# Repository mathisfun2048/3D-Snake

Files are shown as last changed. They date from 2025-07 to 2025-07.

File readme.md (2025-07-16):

# 3-D Snake... but polished

## Description and Exigence

The basic framework of this project came from the undercity hackathon, where me and my teammates were able to scrapyard a prototype to work. This project is the same project but refined, adding a PCB to better manage wires and audio to better communicate to the user when the snake dies. Some minor software improvements have also been made (such as re-working the moving mechanism when the snake reaches the top pannel). 

Here's a pic of our prototype:


## Schematic and PCB

During prototyping, one of the hardest parts of the design was making sure all the gpio pins stayed in place! So, I made a pcb to help with wiring. 

Screenshot 2025-07-16 at 4 08 24 PM

Screenshot 2025-07-16 at 4 08 44 PM

Screenshot 2025-07-16 at 4 09 05 PM

Here's the full wirings with the raspberry pi:
Screenshot 2025-07-16 at 4 35 08 PM

## Firmware

This project is coded in circuitpython to run on a raspberry pi pico. Most of the firmware was written at the hackathon, including the snake's game engine and wrapping mechanisms. With my improvements, a audio mechanism was added, playing a sound when the game is played and a death "game over" sound. Additionally, the joystick movements was revised, however, its effacaciy will only be able to be tested once I build it and get to callibrate the joystick.

## CAD

Here it is! It's pretty bare-bones because I want access to all the gpio and other pins for debugging. 

full case together

Here's what the game will look like with the prototype cad we made at undercity! 



## BOM
|item |quantitiy|tot. cost|FIELD4 |
|---|---|---|---|
|Raspberry Pi Pico |1 |3.94 |https://www.aliexpress.us/item/3256805901509044.html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{"order":"588","eval":"1"}&pdp_npi=4@dis!USD!3.94!0.99!!!28.12!7.05!@2103245417526573392084861e1d15!12000044713099471!sea!US!6423725769!ABX&curPageLogUid=9vH35S108aDJ&utparam-url=scene:search&#124;query_from:&search_p4p_id=202507160215394922763879841710000065438_1 |
|8x8 Neopixel Matrix |5 |0.99 |https://www.aliexpress.us/item/3256806907950230.html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|
|Jumper Wire Kit |1 |2.94 |https://www.aliexpress.us/item/3256801814340687.html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 3.11!USD 2.94!!USD 2.94!!!@2103244817526478142373005ef927!12000018371624182!ct!US!6423725769!!1!0&_gl=1*1n0i64z*_gcl_au*MTk0MzAyNDY5MC4xNzUyNjI3MjM2*_ga*MTc1NDE4NzMwOC4xNzUyNjI3MjM3*_ga_VED1YSGNC7*czE3NTI2NDcxMjIkbzMkZzEkdDE3NTI2NDc4MzAkajE2JGwwJGgw&gatewayAdapt=glo2usa |
|7 Segment Display |2 |0.88 |https://www.aliexpress.us/item/3256806851785862.html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 |
|Joystick |1 |5.54 |https://www.aliexpress.us/item/3256807375670744.html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 |
|Stepper Motor |1 |6.05 |https://www.aliexpress.us/item/3256802068491329.html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 https://www.amazon.com/gp/product/B00PNEQKC0/ref=ewc_pr_img_3?smid=AWQBCGWISS7BL&psc=1 |
|Stepper Motor Driver|1 |2.25 |https://www.aliexpress.us/item/3256809082535036.html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 4.50!USD 2.25!!USD 2.25!!!@2101ead817526549979955339eefa0!12000048551339904!ct!US!6423725769!!1!0&_gl=1*1jo1tpj*_gcl_au*MTk0MzAyNDY5MC4xNzUyNjI3MjM2*_ga*MTc1NDE4NzMwOC4xNzUyNjI3MjM3*_ga_VED1YSGNC7*czE3NTI2NTMwNjIkbzQkZzEkdDE3NTI2NTQ5OTgkajU5JGwwJGgw&gatewayAdapt=glo2usa |
|9v Battery |2 |0 |n/a |
|9V Battery Wire |2 |1.35 |https://www.aliexpress.us/item/3256806021864359.html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 |
|I2C Audio Module |1 |2.13 |https://www.aliexpress.us/item/3256807442706139.html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 2.18!USD 2.13!!USD 2.13!!!@2103146c17526564969422213ebb51!12000041565703118!ct!US!6423725769!!1!0&_gl=1*zdge7z*_gcl_au*MTk0MzAyNDY5MC4xNzUyNjI3MjM2*_ga*MTc1NDE4NzMwOC4xNzUyNjI3MjM3*_ga_VED1YSGNC7*czE3NTI2NTMwNjIkbzQkZzEkdDE3NTI2NTY0ODMkajU4JGwwJGgw&gatewayAdapt=glo2usa |
|Speaker |1 |1.84 |https://www.aliexpress.us/item/3256805513567413.html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{"order":"521","eval":"1"}&pdp_npi=4@dis!USD!1.91!0.99!!!13.62!7.02!@2103247417526569339281477efc58!12000044410928207!sea!US!6423725769!ABX&curPageLogUid=dsVUW3rp1g8F&utparam-url=scene:search&#124;query_from: |
|header pins |1 |2.21 |https://www.aliexpress.us/item/2255800687544049.html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{"order":"3500","eval":"1"}&pdp_npi=4@dis!USD!2.21!0.99!!!2.21!0.99!@2101e07217526574650792034e0f2b!10000010058190554!sea!US!6423725769!ABX&curPageLogUid=oeRbzI77IVV5&utparam-url=scene:search&#124;query_from: |
|pcb |1 |6.22 |https://jlcpcb.com/ |
| | |36.34 | |

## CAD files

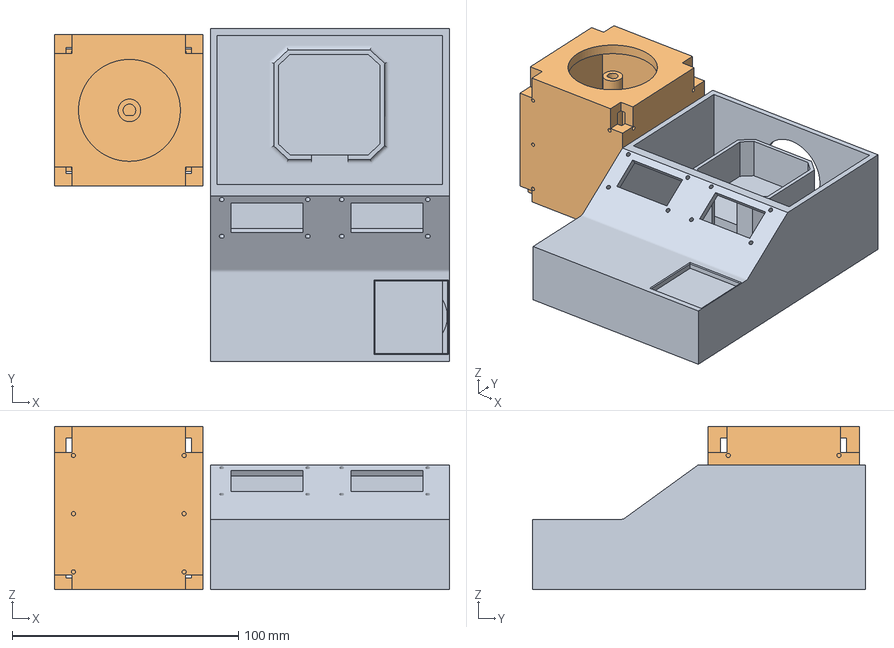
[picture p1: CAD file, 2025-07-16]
Production/Full Case.3mf
174.5 x 147.0 x 72.0 mm
LED Case.stl

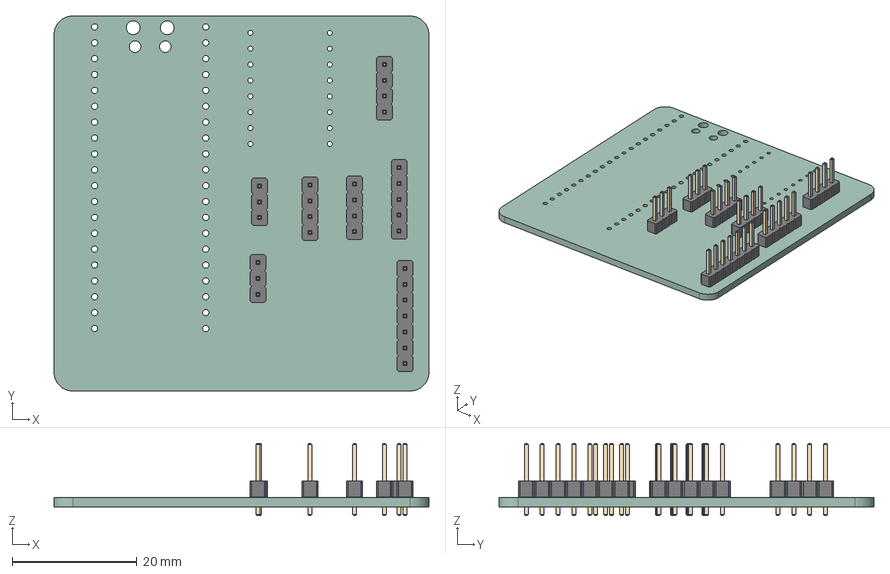
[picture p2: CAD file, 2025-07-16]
CAD/Snake_3D_PCB_STEP.step
60.0 x 60.0 x 11.5 mm
PinHeader_1x03_P2.54mm_Vertical x 2
PinHeader_1x04_P2.54mm_Vertical x 3
PinHeader_1x07_P2.54mm_Vertical
PinHeader_1x05_P2.54mm_Vertical
Snake_3D_KiCAD_PCB

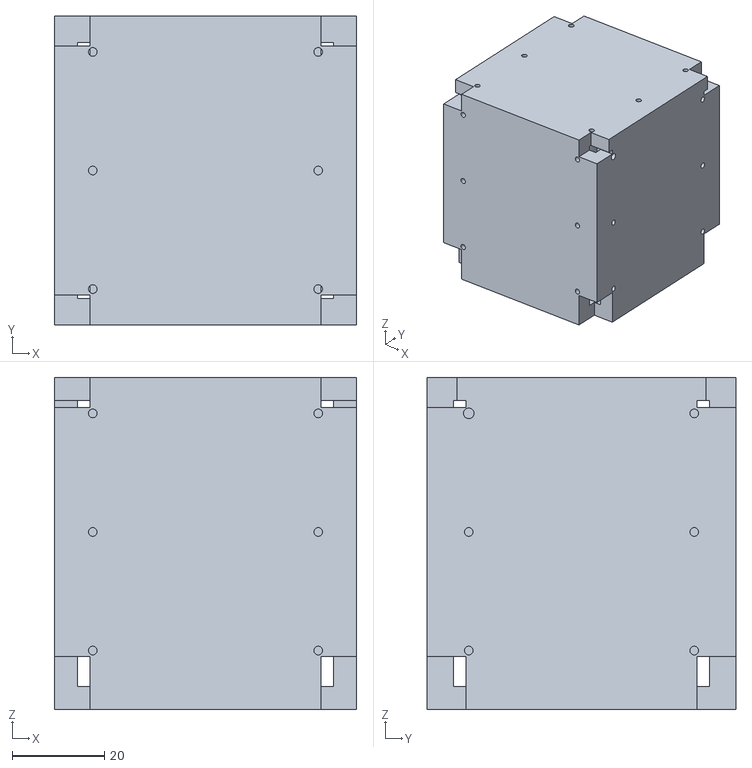
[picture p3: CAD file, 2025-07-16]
Production/LED Case.stl
65.6 x 67.0 x 72.0

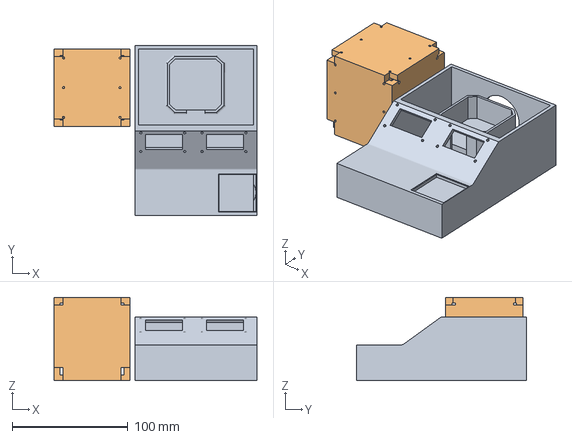
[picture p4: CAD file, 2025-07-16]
Production/BaseCase.3mf
175.7 x 147.0 x 72.0 mm
LED Case.stl

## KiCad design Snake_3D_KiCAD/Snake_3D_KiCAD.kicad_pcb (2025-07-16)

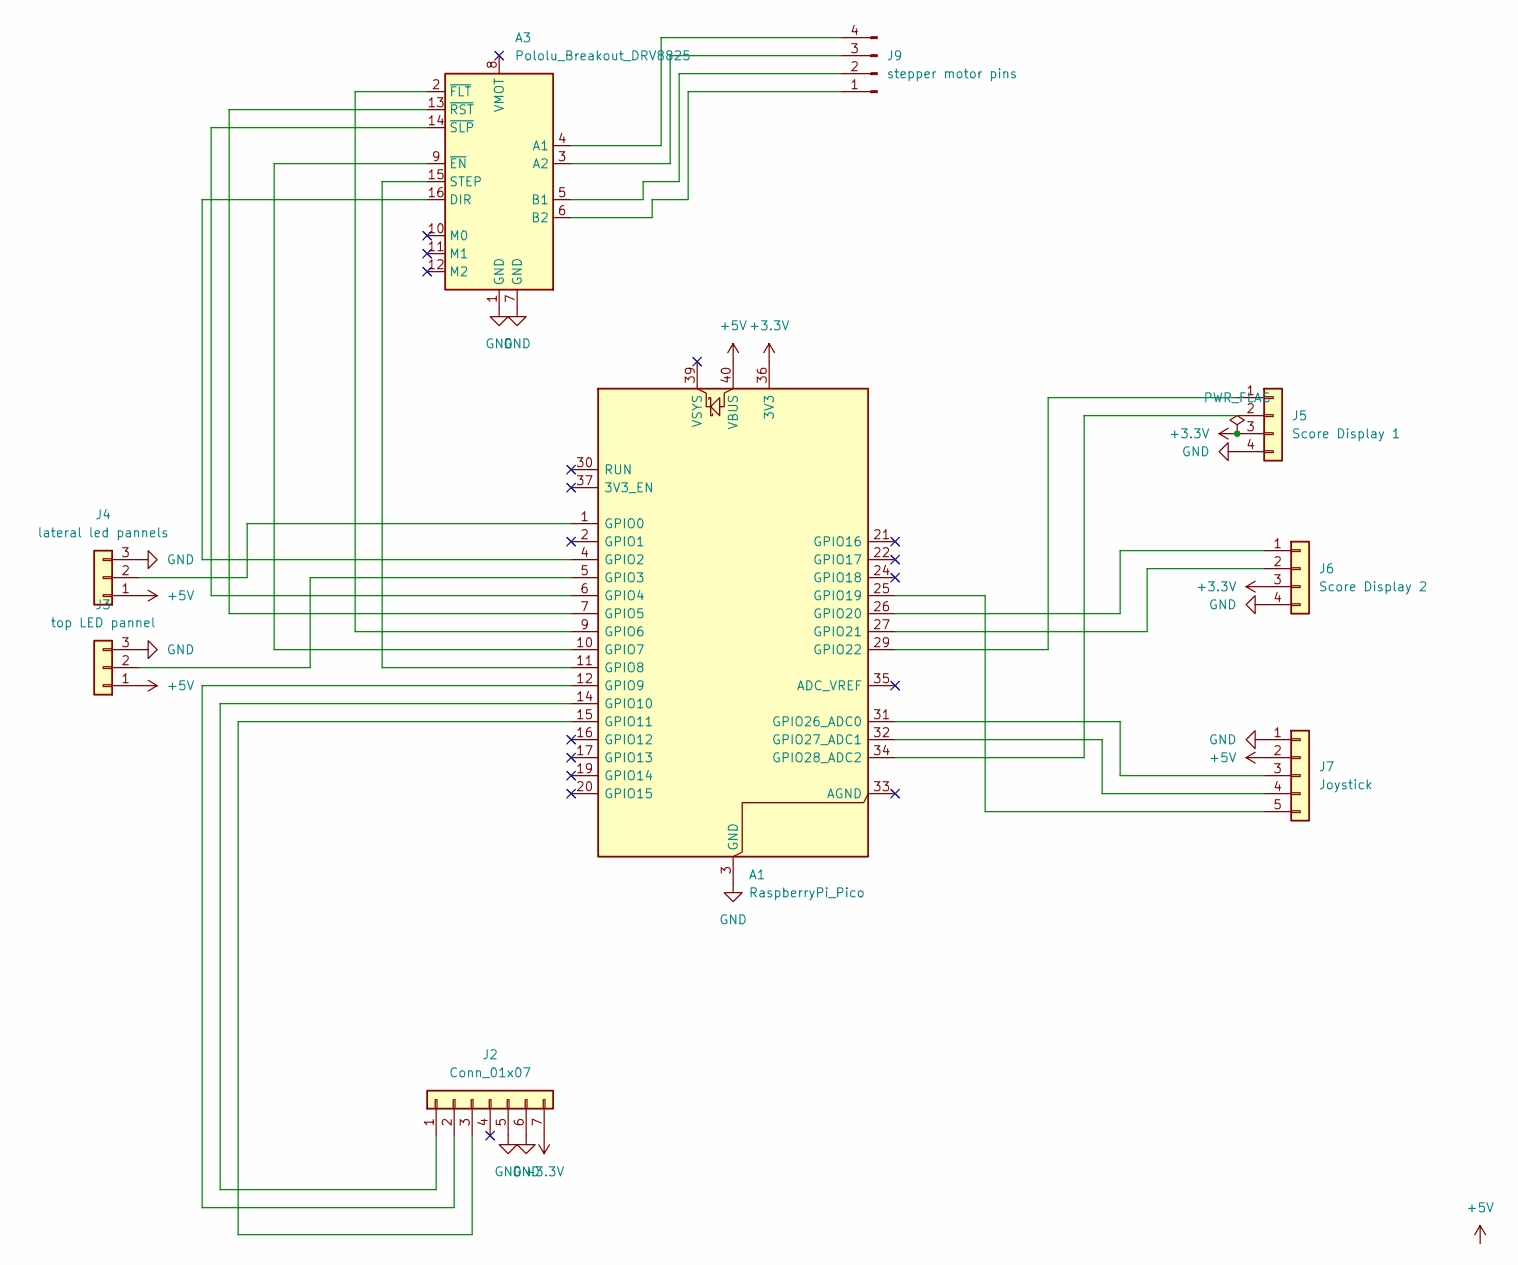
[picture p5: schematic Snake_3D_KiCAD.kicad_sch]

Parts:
A1: RaspberryPi_Pico; RaspberryPi_Pico_Common_Unspecified
A3: Pololu_Breakout_DRV8825; Pololu_Breakout-16_15.2x20.3mm
J2: Conn_01x07; PinHeader_1x07_P2.54mm_Vertical
J3: top LED pannel; PinHeader_1x03_P2.54mm_Vertical
J4: lateral led pannels; PinHeader_1x03_P2.54mm_Vertical
J5: Score Display 1; PinHeader_1x04_P2.54mm_Vertical
J6: Score Display 2; PinHeader_1x04_P2.54mm_Vertical
J7: Joystick; PinHeader_1x05_P2.54mm_Vertical
J9: stepper motor pins; PinHeader_1x04_P2.54mm_Vertical

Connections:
+3.3V: A1.36 (3V3), J2.7, J5.3 (VCC), J6.3 (VCC)
+5V: A1.40 (VBUS), J3.1 (VIN), J4.1 (VIN), J7.2 (+5V)
GND: A1.3 (GND), A1.8 (GND), A1.13 (GND), A1.18 (GND), A1.23 (GND), A1.28 (GND), A1.38 (GND), A3.1 (GND), A3.7 (GND), J2.5, J2.6, J3.3 (GND), J4.3 (GND), J5.4 (GND), J6.4 (GND), J7.1 (GND)
unnamed: A1.1 (GPIO0), J4.2 (DIN_0)
unnamed: A1.4 (GPIO2), A3.16 (DIR)
unnamed: A1.5 (GPIO3), J3.2 (DIN_0)
unnamed: A1.6 (GPIO4), A3.14 (~SLP)
unnamed: A1.7 (GPIO5), A3.13 (~RST)
unnamed: A1.9 (GPIO6), A3.2 (~FLT)
unnamed: A1.10 (GPIO7), A3.9 (~EN)
unnamed: A1.11 (GPIO8), A3.15 (STEP)
unnamed: A1.12 (GPIO9), J2.2
unnamed: A1.14 (GPIO10), J2.1
unnamed: A1.15 (GPIO11), J2.3
unnamed: A1.25 (GPIO19), J7.5 (SW)
unnamed: A1.26 (GPIO20), J6.1 (CLK)
unnamed: A1.27 (GPIO21), J6.2 (DIO)
unnamed: A1.29 (GPIO22), J5.1 (CLK)
unnamed: A1.31 (GPIO26_ADC0), J7.3 (VRX)
unnamed: A1.32 (GPIO27_ADC1), J7.4 (VRY)
unnamed: A1.34 (GPIO28_ADC2), J5.2 (DIO)
unnamed: A3.4 (A1), J9.4 (A1)
unnamed: A3.3 (A2), J9.3 (A2)
unnamed: A3.5 (B1), J9.2 (B1)
unnamed: A3.6 (B2), J9.1 (B2)

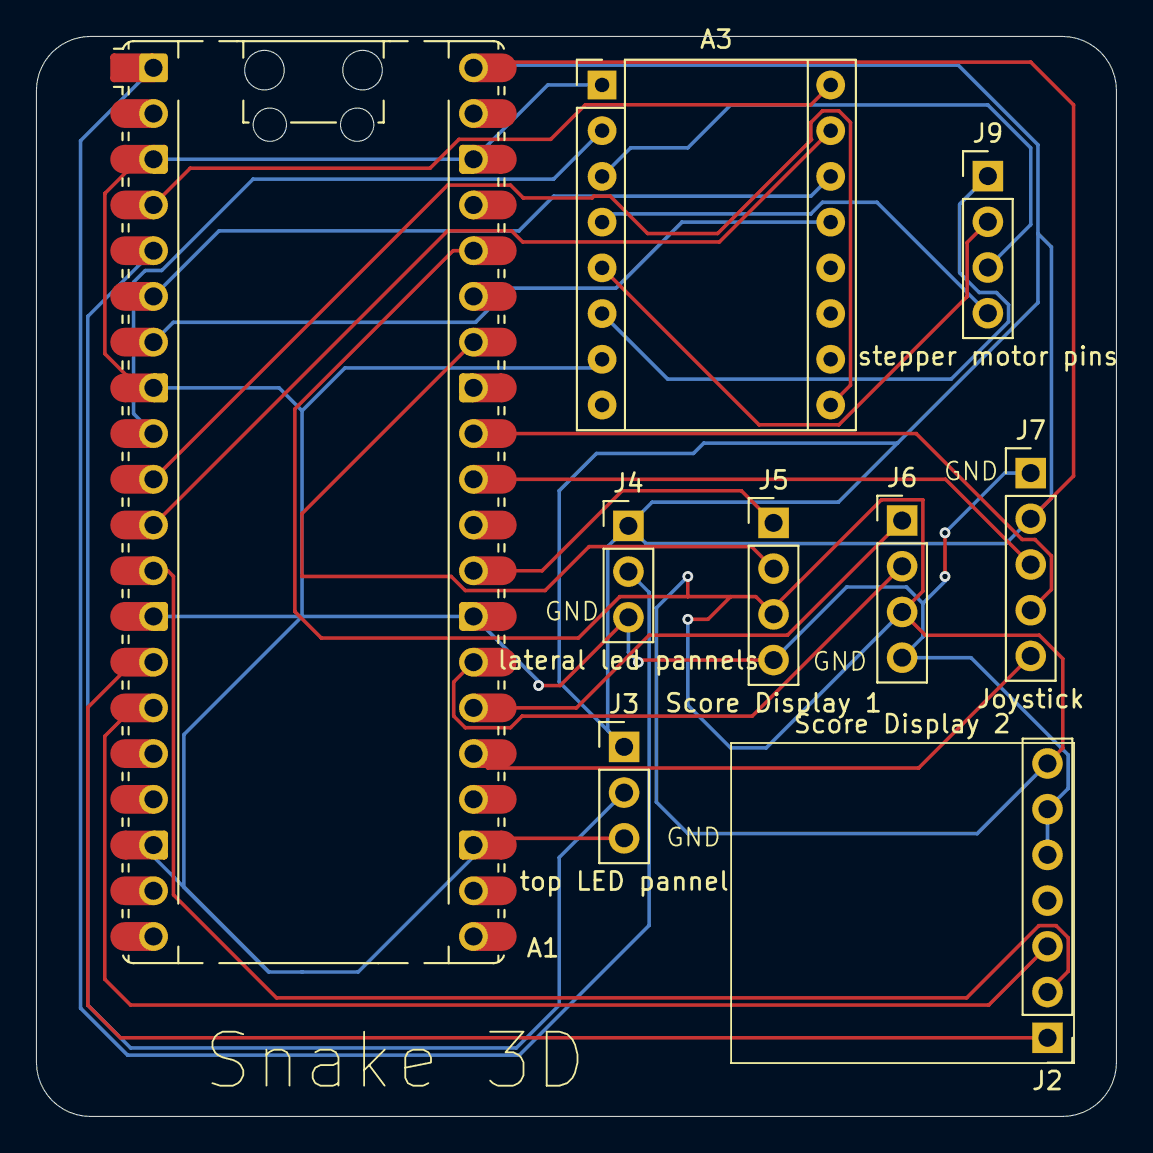
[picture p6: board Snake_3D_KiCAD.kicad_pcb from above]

Board: 2 copper layers, 60.0 x 60.0 mm, 9 parts (0 on the bottom side), 25 nets.

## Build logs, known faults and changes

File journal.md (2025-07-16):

---
title: "Snake 3D"
author: "Arya"
description: "A 3-D port of snake in the third dimension"
created_at: "2025-07-11"
---

# July 15

## 1AM -> 6AM (6 hours)

Started framing the implementation of the music software. Did not have the internet, so this process took a bit longer than normal. 

This is going to be added to the runtime firmware and does the following:

- adds death sound effect! This makes it easier for the user to know when they died
- adds music to make the game feel less boring
- the above point also helps mask the sound of the motor

This is code so I don't know what picutres to attach

Screenshot 2025-07-16 at 6 19 04 PM

# July 16

## 1AM -> 8AM (7 hours)

Thought a pcb would make this look more slick. 

During the processes, I found out that the code I wrote was pretty useless so I started from scratch. 

I researched differnt audio modules, and settled on a MAX98357 which integrates a digital to analog decoder and an amp. yay! With this, ill be able to plug my speaker directly into this module. 

For my speaker, I chose the lowest cost 8 ohm speaker haha

Screenshot 2025-07-16 at 4 08 24 PM

Screenshot 2025-07-16 at 4 08 44 PM

Screenshot 2025-07-16 at 4 09 05 PM

## 3PM -> 5PM (2 hours)

polished the PCB and did a quick cad case to hold the compute box together. Left big openings so the wires can flow through. 

full case together

## 5PM -> 6PM (1 hour)

Polished the code for audio.... hopefully it works!

Screenshot 2025-07-16 at 6 18 46 PM

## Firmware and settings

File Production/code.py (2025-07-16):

import board
import neopixel
import time
import random
import analogio
import pwmio
import tm1637
import digitalio
import digitalio
import time

# starting code for audio

import audiobusio
import audiocore
import array
import math

audio = audiobusio.I2SOut(
    bit_clock=board.GP9,
    word_select=board.GP10,
    data=board.GP11
)

def generate_tone(frequency, duration, sample_rate=22050):
    samples = int(sample_rate * duration)
    tone_array = array.array('H')
    
    for i in range(samples):
        sample = int(32767 * math.sin(2 * math.pi * frequency * i / sample_rate))
        tone_array.append(sample + 32768)
    
    return audiocore.RawSample(tone_array, sample_rate=sample_rate)

def generate_background_music(duration=10, sample_rate=22050):
    samples = int(sample_rate * duration)
    music_array = array.array('H')
    
    for i in range(samples):
        t = i / sample_rate
        note1 = 0.3 * math.sin(2 * math.pi * 440 * t)
        note2 = 0.2 * math.sin(2 * math.pi * 550 * t)
        note3 = 0.1 * math.sin(2 * math.pi * 660 * t)
        
        combined = note1 + note2 + note3
        sample = int(16383 * combined)
        music_array.append(sample + 32768)
    
    return audiocore.RawSample(music_array, sample_rate=sample_rate)


audio = audiobusio.I2SOut(
    bit_clock=board.GP9,
    word_select=board.GP10,
    data=board.GP11


death_sound = generate_tone(200, 0.5)
background_music = generate_background_music()

def play_death_sound():
    if not audio.playing:
        audio.play(death_sound)

def start_background_music():
    if not audio.playing:
        audio.play(background_music, loop=True)

def stop_audio():
    audio.stop()

start_background_music()
)


# ending code for audio

# === Motor Control Setup ===
# GPIO pin assignments for DRV8825
DIR_PIN = board.GP2    # Direction control
STEP_PIN = board.GP8   # Step control
SLP_PIN = board.GP4    # Sleep control (active HIGH)
RST_PIN = board.GP5    # Reset control (active HIGH)
FLT_PIN = board.GP6    # Fault pin (optional, active LOW when fault)
EN_PIN = board.GP7     # Enable control (active LOW)

# Initialize motor control pins
dir_pin = digitalio.DigitalInOut(DIR_PIN)
dir_pin.direction = digitalio.Direction.OUTPUT

step_pin = digitalio.DigitalInOut(STEP_PIN)
step_pin.direction = digitalio.Direction.OUTPUT

sleep_pin = digitalio.DigitalInOut(SLP_PIN)
sleep_pin.direction = digitalio.Direction.OUTPUT

reset_pin = digitalio.DigitalInOut(RST_PIN)
reset_pin.direction = digitalio.Direction.OUTPUT

enable_pin = digitalio.DigitalInOut(EN_PIN)
enable_pin.direction = digitalio.Direction.OUTPUT

# Optional fault pin (input with pull-up)
fault_pin = digitalio.DigitalInOut(FLT_PIN)
fault_pin.direction = digitalio.Direction.INPUT
fault_pin.pull = digitalio.Pull.UP

# Motor configuration
STEPS_PER_90_DEGREES = 50  # 90° rotation
MAX_ROTATION_STEPS = 200   # 360° limit (4 * 50 steps)

# Motor state tracking
current_rotation_steps = 0  # Track total rotation from start position
target_panel = 1  # Current target panel


def init_motor():
    """Initialize the DRV8825 driver"""
    print("Initializing DRV8825 driver...")
    
    # Enable driver (active LOW)
    enable_pin.value = False
    
    # Enable driver (wake up from sleep)
    sleep_pin.value = True
    
    # Release reset (active high)
    reset_pin.value = True
    
    # Set initial direction
    dir_pin.value = True  # True = CW, False = CCW
    step_pin.value = False
    
    time.sleep(0.1)  # Allow driver to initialize
    print("Driver initialized!")

def check_motor_fault():
    """Check if there's a fault condition"""
    return not fault_pin.value  # Fault is active LOW


def step_motor(steps=50, direction=True, delay=0.001):
    """
    Step the motor
    steps: number of steps to take
    direction: True for clockwise, False for counter-clockwise
    delay: delay between steps in seconds
    """
    if check_fault():
        print("ERROR: Fault detected! Check wiring and power supply.")
        return
    
    dir_pin.value = direction
    print(f"Stepping {steps} steps {'CW' if direction else 'CCW'}")
    
    for i in range(steps):
        step_pin.value = True
        time.sleep(delay)
        step_pin.value = False
        time.sleep(delay)
        
        # Check fault every 100 steps
        if i % 100 == 0 and check_fault():
            print(f"Fault detected at step {i}!")
            break

def move_motor(clockwise=True, delay=0.001):
    """
    Move motor exactly 90 degrees (50 steps)
    Based on the step_motor function from tester code
    Returns True if successful, False if failed
    """
    global current_rotation_steps
    
    if check_motor_fault():
        print("ERROR: Fault detected! Check wiring and power supply.")
        return False
    
    # Set direction
    dir_pin.value = clockwise
    print(f"Stepping {STEPS_PER_90_DEGREES} steps {'CW' if clockwise else 'CCW'}")
    
    # Step the motor using the same pattern as tester code
    for i in range(STEPS_PER_90_DEGREES):
        step_pin.value = True
        time.sleep(delay)
        step_pin.value = False
        time.sleep(delay)
        
        # Check fault every 10 steps (more frequent than tester's 100)
        if i % 10 == 0 and check_motor_fault():
            print(f"Fault detected at step {i}!")
            return False
    
    # Update current position
    if clockwise:
        current_rotation_steps += STEPS_PER_90_DEGREES
    else:
        current_rotation_steps -= STEPS_PER_90_DEGREES
    
    print(f"Motor moved successfully. Current position: {current_rotation_steps} steps")
    return True

def calculate_rotation_to_panel(current_panel, target_panel):
    """
    Calculate how many 90° rotations needed to get from current to target panel
    Returns (number_of_rotations, clockwise_direction)
    Positive rotations = clockwise, negative = counter-clockwise
    """
    # Panel arrangement: 1(front) -> 2(right) -> 3(back) -> 4(left) -> 1...
    diff = target_panel - current_panel
    
    # Normalize to shortest path
    if diff > 2:
        diff -= 4  # Go CCW instead
    elif diff < -2:
        diff += 4  # Go CW instead
    
    return diff  # Positive = CW, negative = CCW
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

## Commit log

2025-07-16 set up file structure
    [BaseCase.3mf, Full Case.3mf, LED Case.stl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]
2025-07-16 continued working on pcb
    [Snake_3D_KiCAD.kicad_sch]
2025-07-16 finished pcb design
    [Snake_3D_KiCAD.kicad_pcb, Snake_3D_KiCAD.kicad_sch]
2025-07-16 added gerber files
    [Snake_3D_KiCAD.kicad_pcb, Snake_3D_KiCAD.kicad_sch]
2025-07-16 finished designing 3d case
    [BOM_CSV.csv, Snake_3D_PCB_STEP.step]
2025-07-16 pcb updates
2025-07-16 worked on formatting everything for submission
    [BaseCase.3mf, Full Case.3mf, LED Case.stl]
